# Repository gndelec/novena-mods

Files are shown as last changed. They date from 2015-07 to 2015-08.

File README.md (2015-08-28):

# novena-mods

Mods for the [Novena](https://www.crowdsupply.com/kosagi/novena) open hardware computing platform.

## Contents

* NMFA-01/            - Novena micro fan assembly
* NRFP-01/            - Novena SMA connector panel

## Licence

novena-mods copyright 2015 [AB Open Ltd](http://abopen.com).

<br />This work is licensed under a <a rel="license" href="http://creativecommons.org/licenses/by/4.0/">Creative Commons Attribution 4.0 International License</a>.

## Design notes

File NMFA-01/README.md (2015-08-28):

# Novena Micro Fan Assembly

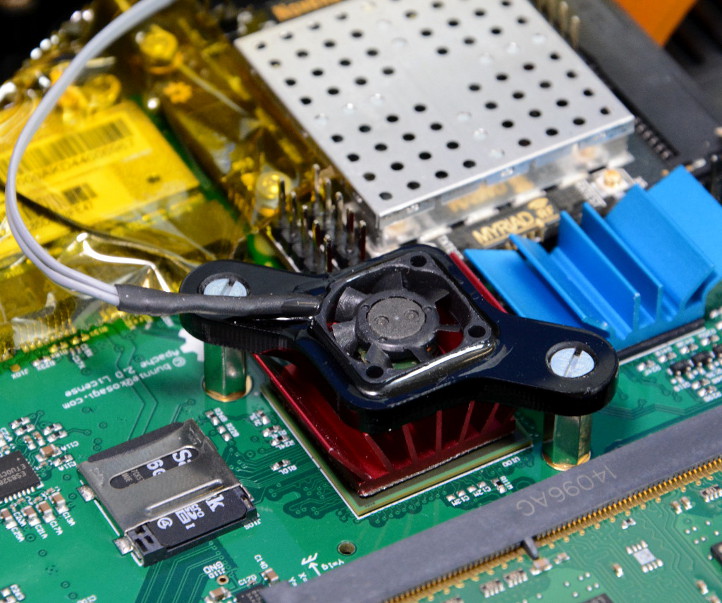
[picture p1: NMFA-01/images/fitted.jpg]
A Novena board with the micro fan assembly fitted


An ultra-slim micro fan complete with fixings for securing over the Novena's Freescale SoC.

Designed for when running computationally-intensive workloads which would otherwise cause the processor to get too hot and the CPU governor to kick in and throttle the clock speed. Typical applications including software-defined radio (SDR) and large parallel software builds.

Power is taken from the front-panel PCB that is fitted to All-in-One Desktop and Laptop configurations, and can be controlled via GPIO (default state is on). The power consumption is ~0.3W.

A ready made assembly can be bought from [Ground Electronics](http://groundelectronics.com/products/novena-micro-fan-assembly).

## Repository contents

* Adobe Illustrator (source)
* SVG
* PDF
* DXF

To be cut from 3mm acrylic. Etched areas to allow for counter-sinking of screw heads (aim for depth of approx 1mm).

## Bill of materials

In addition to the acrylic part the NMFA-01 is made up from:

| Qty | Item |
| --- | --- |
|  1  | SEPA MF15B-05 fan |
|  1  | 2 way 2.5mm pitch JST socket |
|  1  | 30cm 2-core wire |
|  2  | M2.5x10mm F-F hex metal standoff |
|  2  | M2.5x6mm countersunk steel screw |
|  2  | M2.5 fibre washer |

## Assembly

- Remove the two hex screws that are either side of the Freescale SoC (read heatsink).

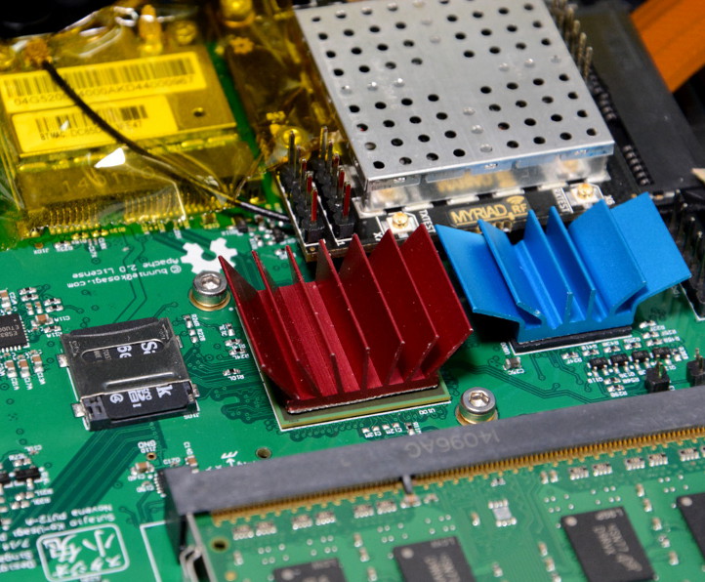
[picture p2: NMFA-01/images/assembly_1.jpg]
Freescale SoC


- Fit the hex standoffs in place of the screws, but be careful not to over-tighten.

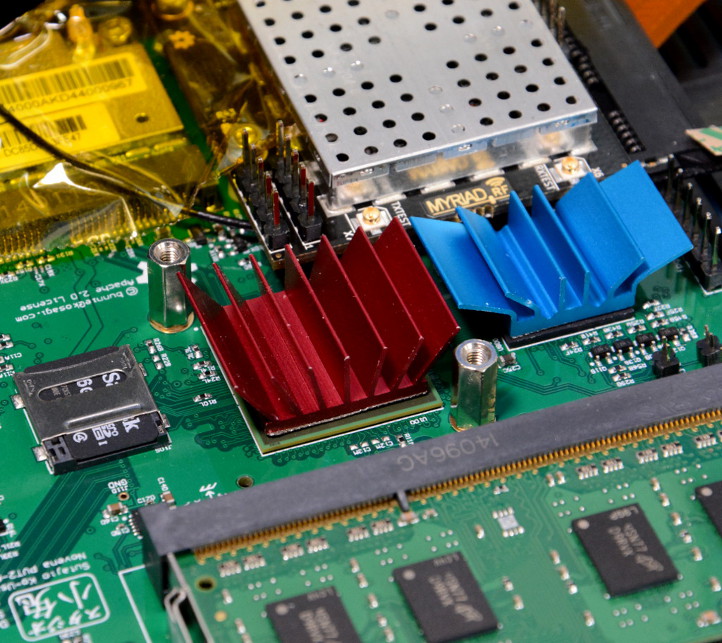
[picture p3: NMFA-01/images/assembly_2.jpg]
Standoffs fitted


- Place the fibre washers on top of the stand-offs, locate the fan assembly on top and secure in place with the M2.5 countersunk srews.

Fan fitted in place

- Plug the power connector into the 5V output on the front panel PCB.

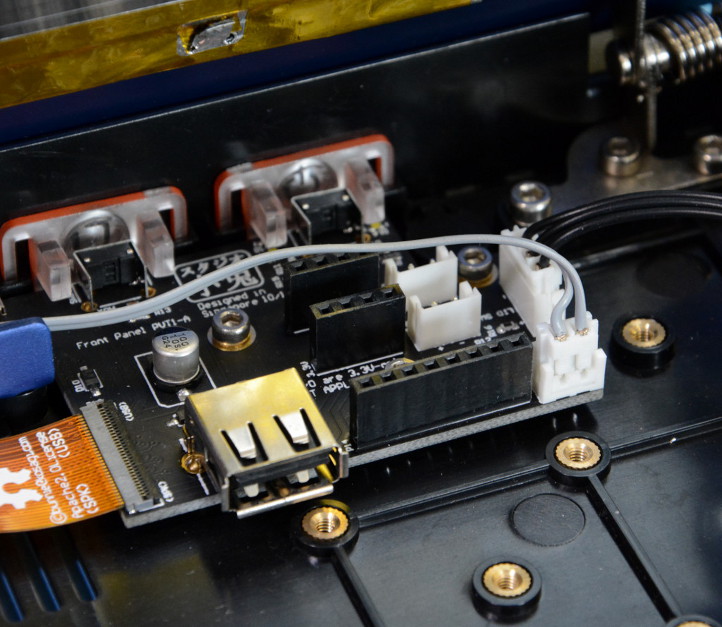
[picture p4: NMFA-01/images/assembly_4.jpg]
Connector inserted


**WARNING: Please note that due to the minimal clearance this must only be used with the screen/lid open and use with it closed could result in hardware failure!**

## Changelog

| Version | Date | Summary
|---|---|---

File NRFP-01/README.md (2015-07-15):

# Novena RF Panel

Front panel for mounting 4 x SMA connectors on the Novena Laptop

cut-prod files exported from software Lasercut 5.1

Sheet stock: 3mm acrylic

Aim to etch acrylic edges to ~1mm thickness

Example cut on a laser cutter with 60W IR tube:

edge etch speed 50, power 44
text etch speed 200, power 20
cut speed 17, power 100

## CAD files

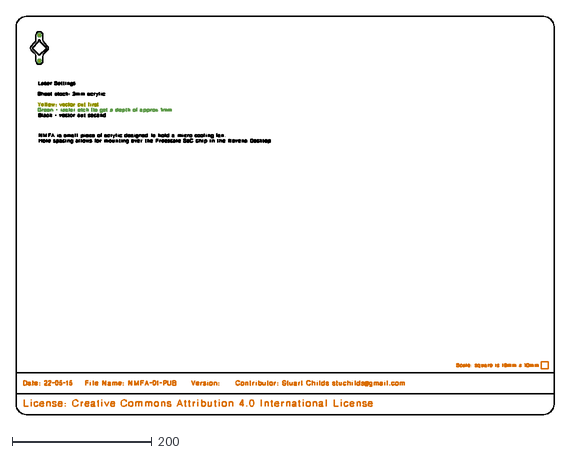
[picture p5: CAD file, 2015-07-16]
NMFA-01/NMFA-01.dxf
770.0 x 570.0

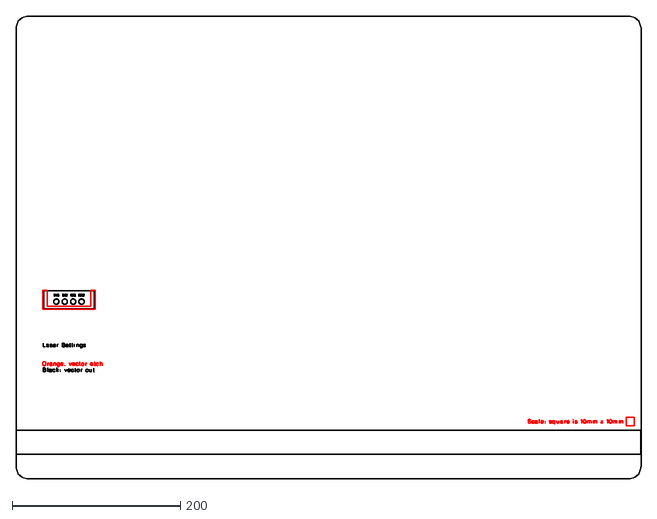
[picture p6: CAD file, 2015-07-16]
NRFP-01/NRFP-01.dxf
743.8 x 550.6

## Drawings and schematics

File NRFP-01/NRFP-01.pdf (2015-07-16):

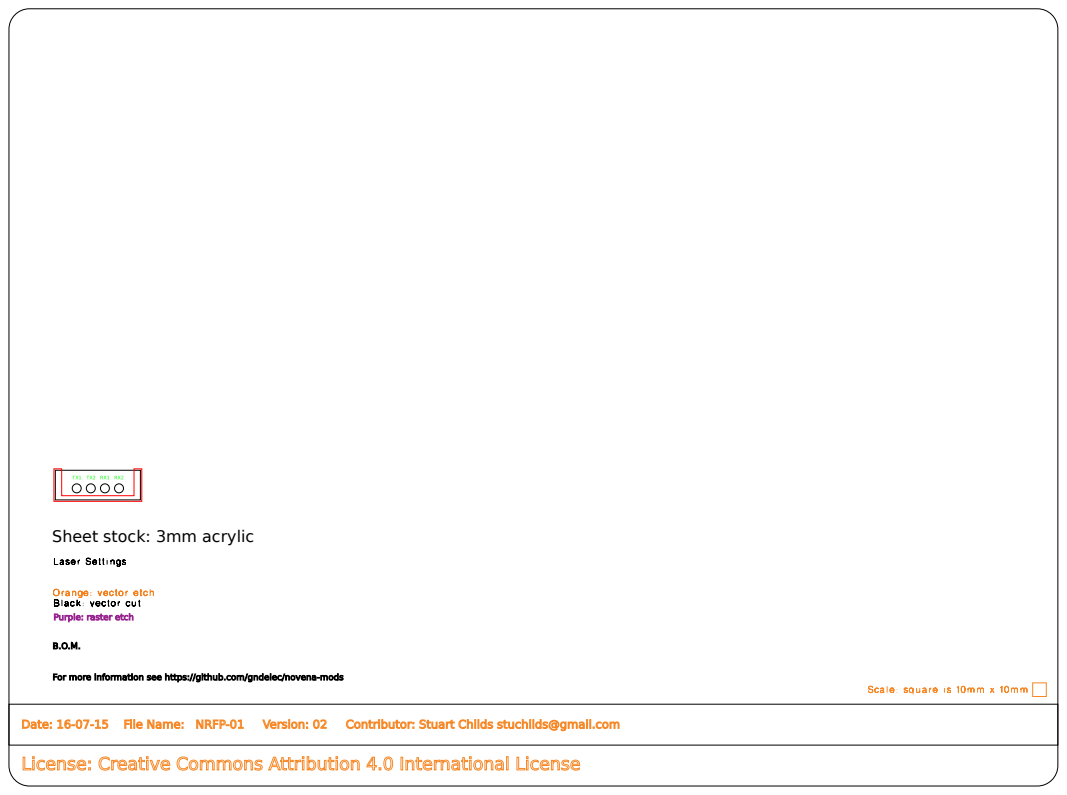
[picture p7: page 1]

Sheet stock: 3mm acrylic

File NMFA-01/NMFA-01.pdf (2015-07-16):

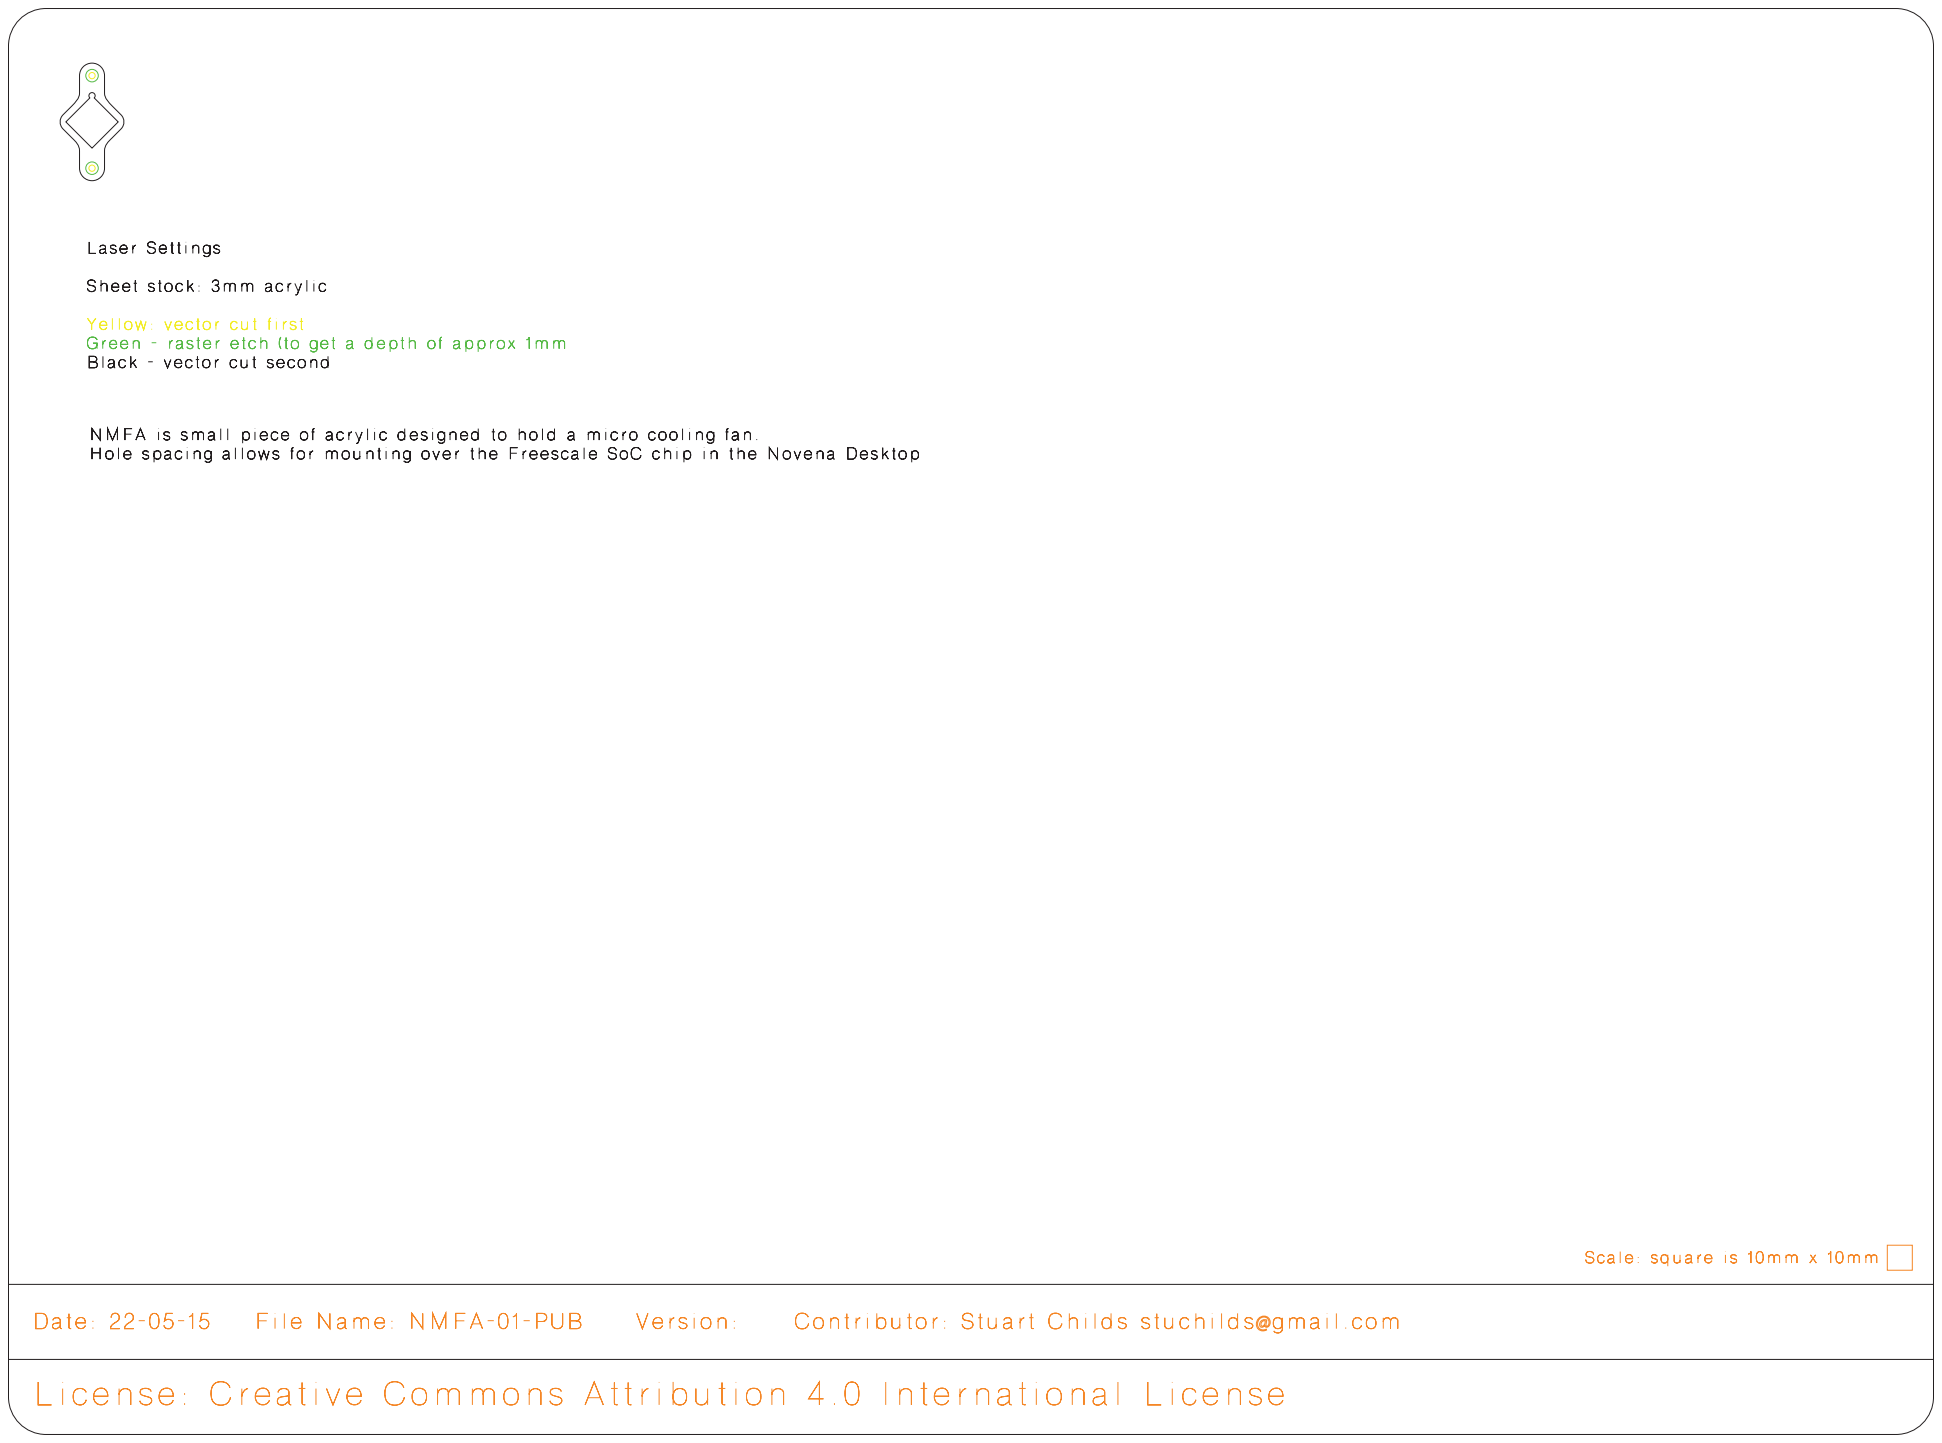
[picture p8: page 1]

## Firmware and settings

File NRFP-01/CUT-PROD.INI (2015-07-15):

[Technics_Laser_Data]
ModifyTechCFG=0
LayersNumber=3
ExportRows=1
ExportColumns=1
ExportRowSpace=0.00000
ExportColumnSpace=0.00000
ExportRowCW=0.00000
ExportColumnCW=0.00000
LogicOrgPositionX=777.41456
LogicOrgPositionY=733.22173
LogicOrgPositionZ=-9999999.00000
AtOnceExport=1
IsTwoLaserWorking=0
TableZeroPositionX=0.00000
TableZeroPositionY=0.00000
OutputTimes=1
DelayTime=0
FeedLength=0.00000
FeedSpeed=5.00000
FeedDelayTime=0
MinX=715.11401
MaxX=777.41456
MinY=710.22061
MaxY=733.22173
ChangeSerialNo=0
ArrayMinX=715.11401
ArrayMaxX=777.41456
ArrayMinY=710.22061
ArrayMaxY=733.22173
LayerColor_0=255
LayerColor_1=65280
LayerColor_2=0
ClipBoxPower=40.00000
ClipBoxPower2=40.00000
ClipBoxOffsetLen=2.00000
ClipBoxSpeed=25.00000
AlignMachineZPos=0.00000
RouteLength=0.00000
RoutePointNumber=0
OffsetLaserPower=0.00000
OffsetWorkSpeedPer=1.00000
ZHeightForLaserFocus=0.00000
OneWorkNeedTimes=0
TotalWorkTimes=0
[CoordSystem_0]
LogicOrgPosition1=777.41456
LogicOrgPosition2=733.22173
LogicOrgPosition3=-9999999.00000
SPLITBLOCK_NUMBER=0
[CreateTechnicsCodeMgr]
PrjHasModifyCFG=1
[TechnicsLayers_0]
TechnicsMode=TECHNICS_LASERCUT
LaserCutConnerPower=100.00000
LaserCutWorkPower=100.00000
LaserCutConnerPower2=10.00000
LaserCutWorkPower2=80.00000
LaserCutFrequency=20000
LaserCutOptimizePathType=1
LaserCutInnerToOuter=1
LaserCutInnerToOuter2=0
LaserCutDownToUpper=0
LaserCutBlockHeight=150.00000
LaserCutAutoSetPathDir=0
LaserCutCicleMinSegNumber=36
LaserCutDisperseLength=0.10000
LaserCutCloseGapLength=0.00000
LaserCutOverlapLength=0.00000
LaserCutAdjustForClose=0
LaserCutQXEnterLength=0.00000
LaserCutDelayMoveTime=0.00000
LaserCutOpenGZDelayTime=0.00000
LaserCutOpenLaserDelayTime=0.00000
LaserCutCloseLaserDelayTime=0.00000
LaserCutDelayTimeAfterCloseLaser=0.00000
LaserCutOneAxisBackLashLength=0.00000
LaserCutTwoAxisBackLashLength=0.00000
LaserCutBackLashAddSpaceLength=8.00000
LaserCutBlowGasType=0
LaserCutAheadBlowGasTimes=0.00000
LaserCutNoCloseGasTimes=0.00000
LaserCutSpeed=17.00000
LaserCutGWAcc=200.00000
LaserCutGWTime=0.01000
LaserCutTrackSize=100
LaserCutLineLength=0.00000
SpaceCutLineLength=0.00000
bSpaceLineFirst=0
LaserCutAdjustMove=0
LaserCutAdjustMoveDelay=0.00000
LaserCutUpLen=0.00000
LaserCutCircleSpeedNum=6
LaserCutCircleSpeed0_MinR=0.00000
LaserCutCircleSpeed0_MaxR=0.55000
LaserCutCircleSpeed0_Speed=15.00000
LaserCutCircleSpeed1_MinR=0.55000
LaserCutCircleSpeed1_MaxR=1.05000
LaserCutCircleSpeed1_Speed=20.00000
LaserCutCircleSpeed2_MinR=1.05000
LaserCutCircleSpeed2_MaxR=1.55000
LaserCutCircleSpeed2_Speed=25.00000
LaserCutCircleSpeed3_MinR=1.55000
LaserCutCircleSpeed3_MaxR=2.05000
LaserCutCircleSpeed3_Speed=30.00000
LaserCutCircleSpeed4_MinR=2.05000
LaserCutCircleSpeed4_MaxR=3.05000
LaserCutCircleSpeed4_Speed=35.00000
LaserCutCircleSpeed5_MinR=3.05000
LaserCutCircleSpeed5_MaxR=4.05000
LaserCutCircleSpeed5_Speed=40.00000
GROUP_ROWS_0=1
GROUP_COLUMNS_0=1
GROUP_ROWSPACE_0=0.00000
GROUP_COLUMNSPACE_0=0.00000
GROUP_ROWCWSPACE_0=0.00000
GROUP_COLUMNCWSPACE_0=0.00000
GROUP_MINX_0=716.11428
GROUP_MAXX_0=776.41428
GROUP_MINY_0=711.22224
GROUP_MAXY_0=732.22224
[TechnicsLayers_255]
TechnicsMode=TECHNICS_LASERENGRAVE
LaserCutConnerPower=100.00000
LaserCutWorkPower=100.00000
LaserCutConnerPower2=10.00000
LaserCutWorkPower2=80.00000
LaserCutFrequency=20000
LaserCutOptimizePathType=1
LaserCutInnerToOuter=1
LaserCutInnerToOuter2=0
LaserCutDownToUpper=0
LaserCutBlockHeight=150.00000
LaserCutAutoSetPathDir=0
LaserCutCicleMinSegNumber=36
LaserCutDisperseLength=0.10000
LaserCutCloseGapLength=0.00000
LaserCutOverlapLength=0.00000
LaserCutAdjustForClose=0
LaserCutQXEnterLength=0.00000
LaserCutDelayMoveTime=0.00000
LaserCutOpenGZDelayTime=0.00000
LaserCutOpenLaserDelayTime=0.00000
LaserCutCloseLaserDelayTime=0.00000
LaserCutDelayTimeAfterCloseLaser=0.00000
LaserCutOneAxisBackLashLength=0.00000
LaserCutTwoAxisBackLashLength=0.00000
LaserCutBackLashAddSpaceLength=8.00000
LaserCutBlowGasType=0
LaserCutAheadBlowGasTimes=0.00000
LaserCutNoCloseGasTimes=0.00000
LaserCutSpeed=25.00000
LaserCutGWAcc=200.00000
LaserCutGWTime=0.01000
LaserCutTrackSize=100
LaserCutLineLength=0.00000
SpaceCutLineLength=0.00000
bSpaceLineFirst=0
LaserCutAdjustMove=0
LaserCutAdjustMoveDelay=0.00000
LaserCutUpLen=0.00000
LaserCutCircleSpeedNum=6
LaserCutCircleSpeed0_MinR=0.00000
LaserCutCircleSpeed0_MaxR=0.55000
LaserCutCircleSpeed0_Speed=15.00000
LaserCutCircleSpeed1_MinR=0.55000
LaserCutCircleSpeed1_MaxR=1.05000
LaserCutCircleSpeed1_Speed=20.00000
LaserCutCircleSpeed2_MinR=1.05000
LaserCutCircleSpeed2_MaxR=1.55000
LaserCutCircleSpeed2_Speed=25.00000
LaserCutCircleSpeed3_MinR=1.55000
LaserCutCircleSpeed3_MaxR=2.05000
LaserCutCircleSpeed3_Speed=30.00000
LaserCutCircleSpeed4_MinR=2.05000
LaserCutCircleSpeed4_MaxR=3.05000
LaserCutCircleSpeed4_Speed=35.00000
LaserCutCircleSpeed5_MinR=3.05000
LaserCutCircleSpeed5_MaxR=4.05000
LaserCutCircleSpeed5_Speed=40.00000
LaserEngravePower=44.00000
LaserEngravePower2=60.00000
LaserEngraveFrequency=20000
LaserEngraveSpeed=50.00000
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

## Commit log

2015-07-16 Revised hole position down - prevents fouling on screen bezel
    [NRFP-01.dxf]
2015-08-28 Added NMFA-01 BOM and instructions
